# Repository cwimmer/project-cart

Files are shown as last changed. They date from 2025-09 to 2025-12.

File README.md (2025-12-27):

# Project Cart

The Project Cart is designed to hold [Euro Containers](https://en.wikipedia.org/wiki/Euro_container) (nominal size 400×300 mm or smaller) to organize project parts and tools. This cart provides a convenient storage solution for multiple projects at your workbench. To switch projects, simply return parts to their containers or place them on the cart, then roll it away. Roll in another cart to continue working seamlessly.

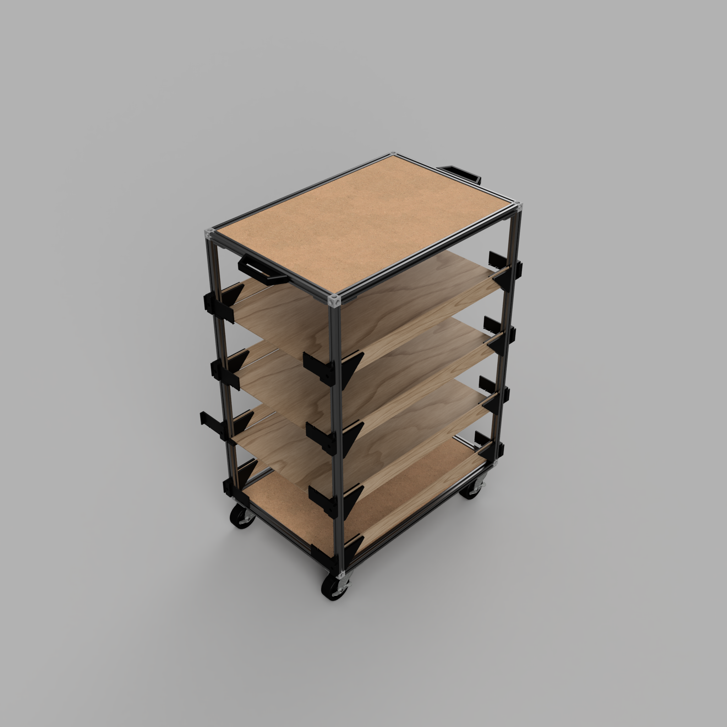
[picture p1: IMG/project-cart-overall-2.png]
Wheeled project cart with multiple shelves holding Euro containers in a workshop setting, featuring a black aluminum frame with yellow casters and organized storage compartments


Please use the [latest released version](https://github.com/cwimmer/project-cart/releases/latest).  The main branch might have partial changes committed.

## Capabilities required to build this project

- Metric hex wrenches
- Large square
- FDM 3D Printer
- Ability to cut sheet goods square to accurate dimensions
  - Table saw or track saw are easiest.  Other methods will work.
- Metric ruler (800mm or longer)

## Table of Contents

- [Readme](README.md) - This file
- [Bill of Materials](BOM.md) - Specifications of parts included in this assembly
- [Assembly Instructions](ASSEMBLY.md) - Assembly Instructions
- [Changelog](CHANGELOG.md) - Chronologically ordered list of notable changes for each version of a project
- [Material Defaults](MATERIAL_DEFAULTS.md) - Descriptions of materials where not otherwise specified.
- [Part Orientation](PART_ORIENTATION.md) - Orientation instructions for 3D printing
- [On Suppliers](ON_SUPPLIERS.md) - Discussion of how to source parts for this assembly
- [Acknowledgements](ACKNOWLEDGEMENTS.md) - Acknowledgements of other authors included either for reference or inspiration

## General Notes

1. Unless otherwise specified, dimensions are in millimeters.
2. The CAD diagrams in the CAD directory are the authoritative definition of this assembly.

## License

Unless otherwise noted:

- **All written content and images:** © Charles Wimmer, licensed under [Creative Commons Attribution 4.0 International](https://creativecommons.org/licenses/by/4.0/).
- **All hardware design files (e.g., STL, CAD, PCB):** Licensed under the [CERN Open Hardware License v2 – Strongly Reciprocal](https://ohwr.org/cern_ohl_s_v2.txt).
- **All code and scripts:** Licensed under the [MIT License](https://opensource.org/licenses/MIT).

## Images

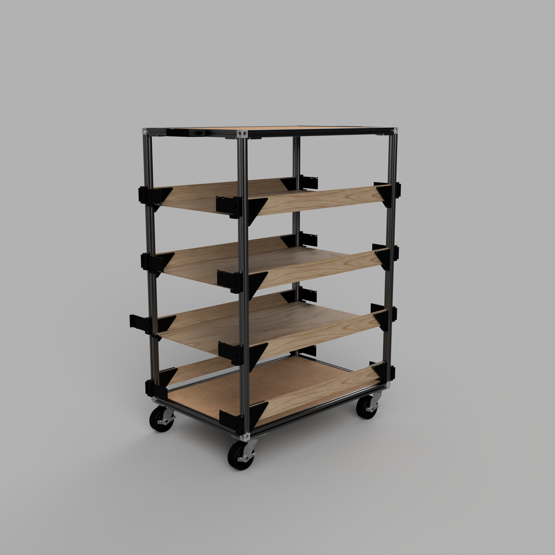
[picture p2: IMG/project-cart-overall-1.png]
Overall 1

Overall 2
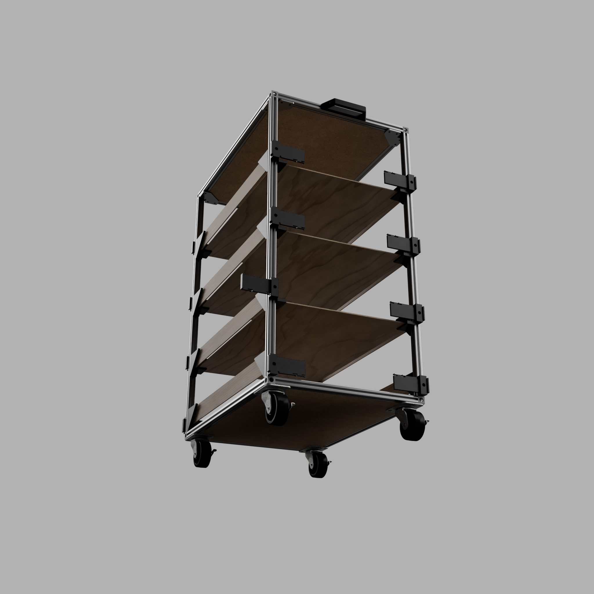
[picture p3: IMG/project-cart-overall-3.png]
Overall 3

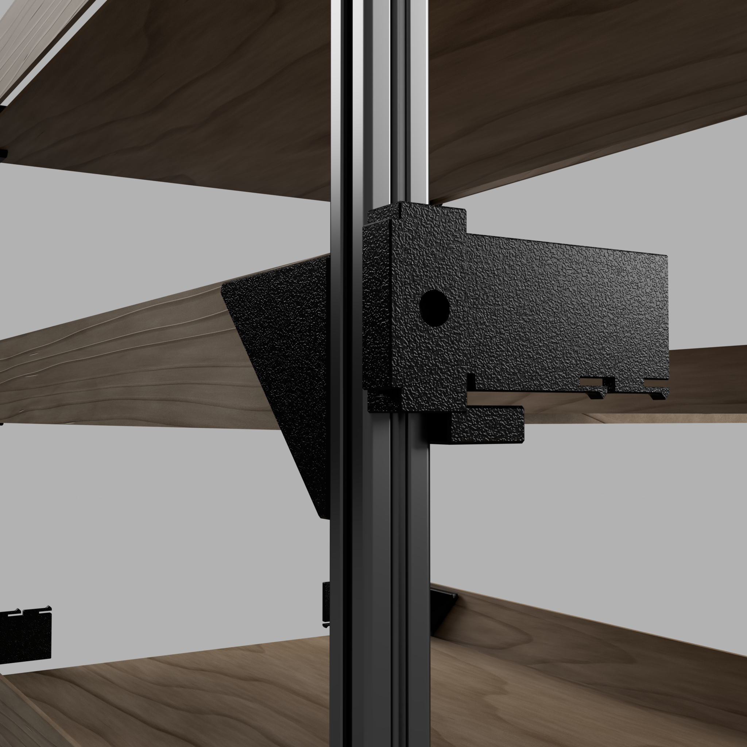
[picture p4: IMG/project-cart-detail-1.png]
Detail 1

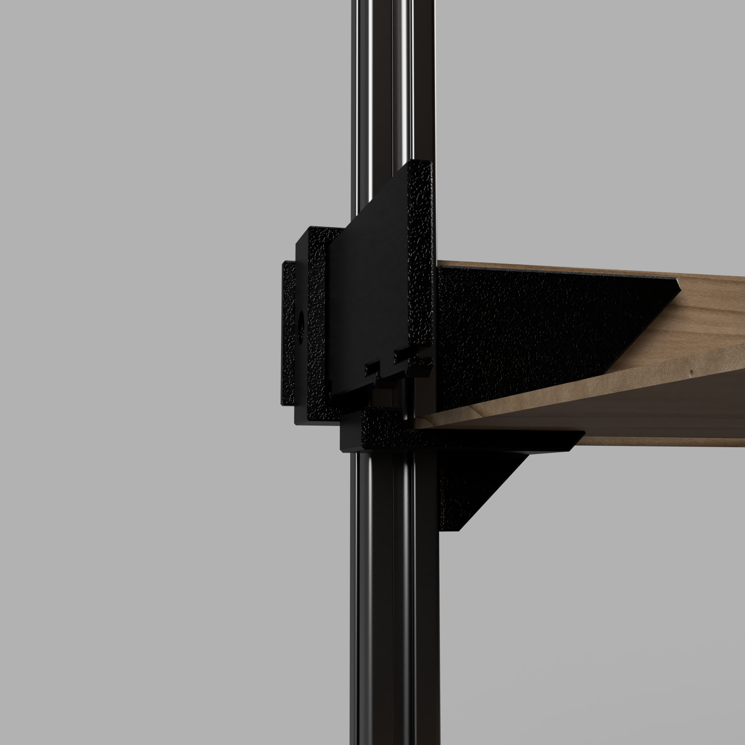
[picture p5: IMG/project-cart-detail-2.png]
Detail 2

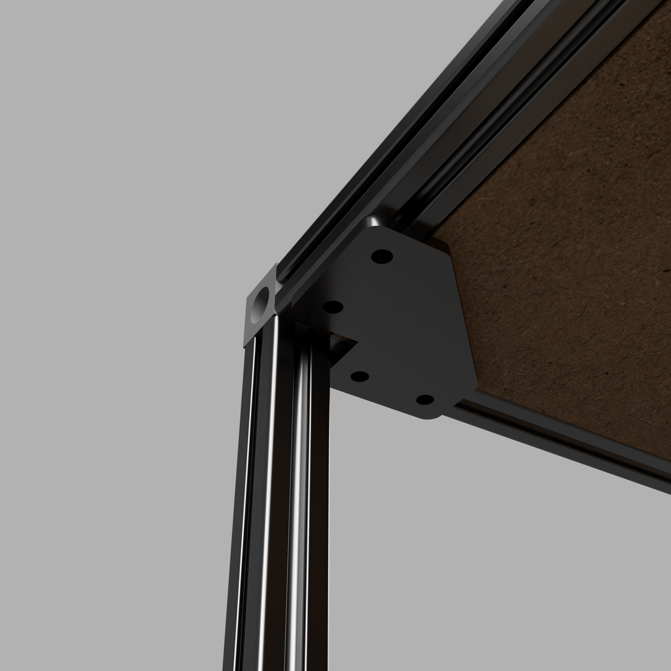
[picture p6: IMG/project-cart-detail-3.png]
Detail 3

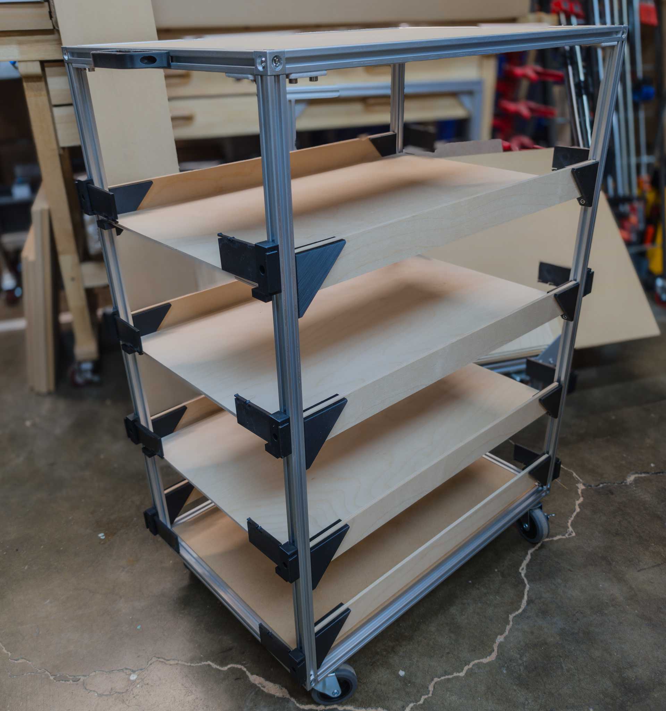
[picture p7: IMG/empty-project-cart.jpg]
Real Image empty

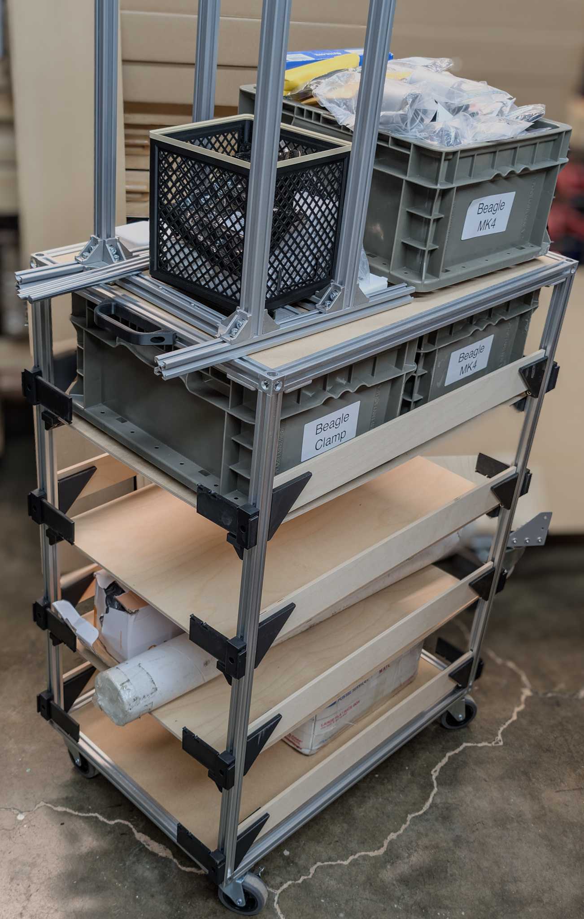
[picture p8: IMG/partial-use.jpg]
Partial use


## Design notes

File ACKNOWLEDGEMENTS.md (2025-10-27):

# Acknowledgements

- [Corner Cube](https://grabcad.com/library/corner-cube-vslot-2020-3-ways-1) model by [Steepy](https://grabcad.com/steepy-1)
- [Caster](https://www.mcmaster.com/2358t26/) model by McMaster
- [Extrusion](https://www.mcmaster.com/5537T9) model by McMaster
- [Keep a Changelog](https://keepachangelog.com/en/1.1.0/)

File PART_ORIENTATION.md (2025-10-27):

# Part Orientation

These parts have been successfully printed using [Voron Print Settings](https://docs.vorondesign.com/sourcing.html) in ASA.

Orient with the long diagonal side on the print bed to resist layer line separation under load.

## PC-001/PC-002 Shelf Bracket

- 12 × 2020 Shelf Bracket ([STEP](STEP)/[STL](STL))
  - Mirror 6 of them.  Left are different from right.

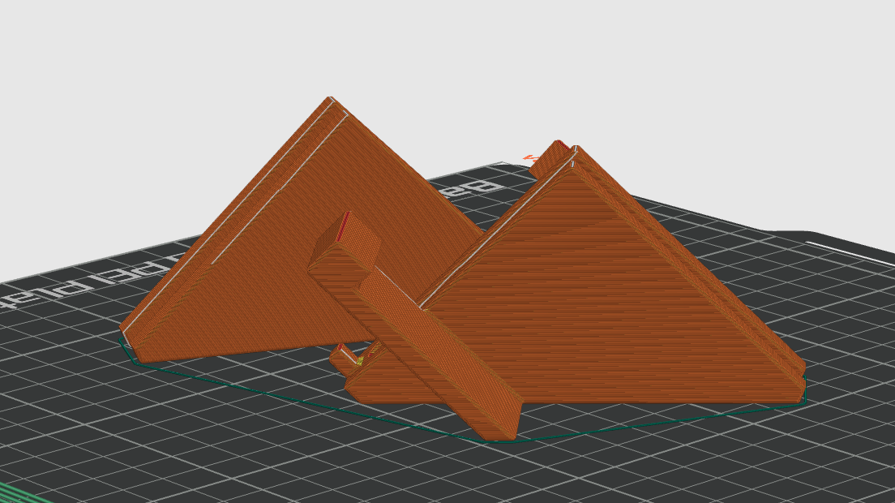
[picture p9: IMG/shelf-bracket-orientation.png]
Shelf Bracket


## PC-003 Side Bracket

- 4 × 2020 Side Bracket ([STEP](STEP)/[STL](STL))

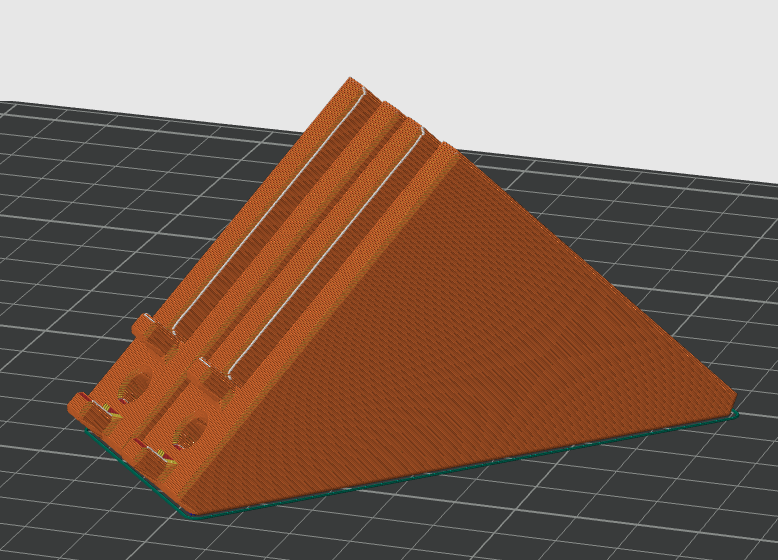
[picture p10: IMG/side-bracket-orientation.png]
Side Bracket


## PC-004 Latch

- 16 x 2020 Latch ([STEP](STEP)) Optional, but suggested.
  - Must split the STEP file into separate objects to print.
  - Supports are integrated into the model and must be removed before installation

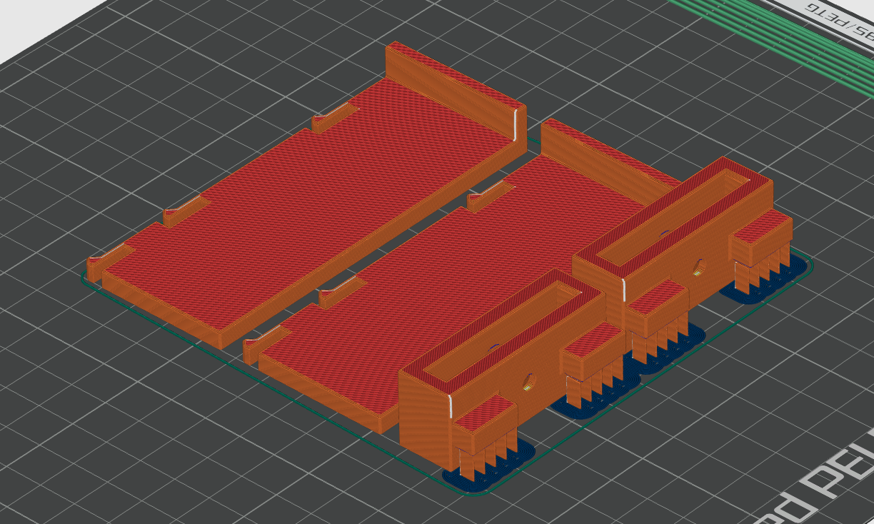
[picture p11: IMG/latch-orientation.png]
Latch


## PC-005 Shelf Bracket Spacer

- 1 x Shelf Bracket Spacer([STEP](STEP)/[STL](STL)). Optional, but suggested.

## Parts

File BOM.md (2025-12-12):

# Bill of Materials

Most components are listed from McMaster for convenience; feel free to substitute equivalent items from other suppliers.

The [2020 Corner Shelf Supports](https://github.com/cwimmer/2020-corner-shelf-support) (PC-109) are a part I designed.  You can produce your own or [contact me](https://the-playground.net/Whoami) if you would to purchase some.  These may theoretically be 3D printed, but I wouldn't suggested for any but the lightest laod.

## 3D Printed Components

| Part Number | Common Name | Quantity | Description | Material | Finish | Sources | Notes |
| --- | --- | --- | --- | --- | --- | --- | --- |
| PC-001 | Shelf Bracket Left | 6 | Support bracket for internal shelf and side panel | ASA (Substitute as needed) | | [STL](STL)/[STEP](STEP)/[CAD](CAD) | See [PART_ORIENTATION.md](PART_ORIENTATION.md) |
| PC-002 | Shelf Bracket Right | 6 | Support bracket for internal shelf and side panel | ASA (Substitute as needed) | | [STL](STL)/[STEP](STEP)/[CAD](CAD) | See [PART_ORIENTATION.md](PART_ORIENTATION.md) |
| PC-003 | Side Bracket | 4 | Support bracket for bottom shelf side panel | ASA (Substitute as needed) | | [STL](STL)/[STEP](STEP)/[CAD](CAD) | See [PART_ORIENTATION.md](PART_ORIENTATION.md) |
| PC-004 | Latch | 16 | Widgets to perform foo | ASA (Substitute as needed) | | [STL](STL)/[STEP](STEP)/[CAD](CAD) | See [PART_ORIENTATION.md](PART_ORIENTATION.md) |
| PC-005 | Shelf Bracket Spacer | 1 | Assembly jig | Any | | [STL](STL)/[STEP](STEP)/[CAD](CAD) | |

## Non-fasteners

| Part Number | Common Name | Quantity | Description | Material | Finish | Sources | Notes |
| --- | --- | --- | --- | --- | --- | --- | --- |
| PC-101 | 800mm aluminum extrusion| 4 | 2020 t-slot aluminum extrusion | Aluminum alloy (Magnesium and Silicon 6xxx ) | Any |McMaster: [5537T9](https://www.mcmaster.com/5537T9)<br>Amazon US: [B08PQTDPB3](https://www.amazon.com/dp/B08PQTDPB3) | |
| PC-102 | 400mm aluminum extrusion| 4 | 2020 t-slot aluminum extrusions | Aluminum alloy (Magnesium and Silicon 6xxx ) | Any | McMaster: [5537T9](https://www.mcmaster.com/5537T9)<br>Amazon US: [B0874387ZB](https://www.amazon.com/dp/B0874387ZB) | |
| PC-103 | 600mm aluminum extrusion | 4 | 2020  t-slot aluminum extrusions | Aluminum alloy (Magnesium and Silicon 6xxx ) | Any |McMaster: [5537T9](https://www.mcmaster.com/5537T9)<br>Amazon US: [B08CN9L94Q](https://www.amazon.com/dp/B08CN9L94Q) | |
| PC-104 | Corner Brackets | 8 | Outside Corner Bracket for 20 mm High Single Rail | Aluminum alloy (Magnesium and Silicon 6xxx ) | Any| McMaster: [5537T286](https://www.mcmaster.com/5537T286)<br>Amazon US: [B0CZRH2RW4](https://www.amazon.com/dp/B0CZRH2RW4) |  |
| PC-105 | Casters | 4 | 3 inch diameter solid rubber wheel swivel plate caster.  120lb load minimum | Zinc-Plated Steel and rubber| Any | McMaster [2358T26](https://www.mcmaster.com/2358T26)<br>Amazon US: [B0D8L62MFL](https://www.amazon.com/dp/B0D8L62MFL) |  |
| PC-106 | Interior Shelves | 3| 399mm x 629mm x 3mm (1/8") plywood panel | Baltic birch or similar | Any| [Woodworkers Source](https://www.woodworkerssource.com/plywood/18-baltic-birch-plywood-pack-choose-your-size.html) |  |
| PC-107 | Side Panels | 8 | 50mm x 599mm x 3mm (1/8") plywood panel | Baltic birch or similar | Any| [Woodworkers Source](https://www.woodworkerssource.com/plywood/18-baltic-birch-plywood-pack-choose-your-size.html) |  |
| PC-108 | Top/Bottom Shelves | 2 | 399mm x 599mm x 18mm (3/4") Plywood or particle board panel | MDF or similar | Any | [Woodworkers Source](https://www.woodworkerssource.com/mdf-34-free-shipping.html) |  |
| PC-109 | 2020 Corner Shelf Brackets | 4 |Custom joining plate for 2020 extrusions |Aluminum alloy (Magnesium and Silicon 6xxx )  | Any | [https://github.com/cwimmer/2020-corner-shelf-support](https://github.com/cwimmer/2020-corner-shelf-support)<br>- 3D Printed (NOT SUGGESTED)<br>- CNC yourself<br>- [Contact me](https://the-playground.net/Whoami) to acquire |  |

## Fasteners

| Part Number | Common Name | Quantity | Description | Material | Finish | Sources | Notes |
| --- | --- | --- | --- | --- | --- | --- | --- |
| **M6** | | | | | | | |
| PC-201 | M6 x 12mm BHCS | 24 | M6 × 1.0 mm thread Stainless Steel Button Head Cap Screws | 18-8 or 304 Stainless Steel | Any | McMaster: [92095A226](https://www.mcmaster.com/92095A226/)<br>Bolt Depot: [6644](https://boltdepot.com/Product-Details?product=6644) |  |
| PC-202 | M6 x 30mm SHCS | 4 | M6 × 1.0 mm thread Stainless Steel Socket Head Cap Screws | 18-8 or 304 Stainless Steel |Any|McMaster: [91292A139](https://www.mcmaster.com/91292A139/)<br>Bolt Depot: [6421](https://boltdepot.com/Product-Details?product=6421) | |
| PC-203  | M6 Washers | 4 | M6 General Purpose Washers| 18-8 or 304 Stainless Steel | Any| McMaster: [93475A250](https://www.mcmaster.com/93475A250/)<br>Bolt Depot: [4516](https://boltdepot.com/Product-Details?product=4516)| |
| **M5** | | | | |
|PC-204 | M5 x 8mm SHCS | 16| M5 × 0.8 mm thread Stainless Steel Socket Head Cap Screws | 18-8 or 304 Stainless Steel | Any| McMaster: [91292A191](https://www.mcmaster.com/91292A191/)<br>Bolt Depot: [6406](https://boltdepot.com/Product-Details?product=6406) |  |
|PC-205  | M5 x 14mm SHCS |16| M5 × 0.8 mm thread Stainless Steel Socket Head Cap Screws | 18-8 or 304 Stainless Steel |Any| McMaster: [91292A058](https://www.mcmaster.com/91292A058/)<br>Bolt Depot: [20261](https://boltdepot.com/Product-Details?product=20261) |  |
|PC-206  | M5 Washers | 8 | M5 General Purpose Washers| 18-8 or 304 Stainless Steel |Any|McMaster:  [93475A240](https://www.mcmaster.com/93475A240/)<br>Bolt Depot: [4515](https://boltdepot.com/Product-Details?product=4515)|  |
|PC-207 | 2020 M5 Drop in nuts | 52 | 2020 M5 Hammer Head Nuts | Carbon or Stainless Steel | Any| Amazon US: [B01FOC6A8E](https://www.amazon.com/dp/B01FOC6A8E) | |
|PC-210 | M5 x 10mm SHCS | 8 | M5 × 0.8 mm thread Stainless Steel Socket Head Cap Screws | 18-8 or 304 Stainless Steel | Any| McMaster: [91292A124](https://www.mcmaster.com/91292A124/)<br>Bolt Depot: [6407](https://boltdepot.com/Product-Details?product=6407) |  |
| **M4**| | | | |
| PC-208 | M4 x 10mm FHCS |16|  M4 × 0.7 mm thread Stainless Steel Socket Head Cap Screws | 18-8 or 304 Stainless Steel|Any|McMaster: [91292A116](https://www.mcmaster.com/91292A116/)<br>Bolt Depot: [6664](https://boltdepot.com/Product-Details?product=6664) |  |
| PC-209| 2020 M4 Drop in Nuts | 16| 2020 M4 Drop nuts | Carbon Steel | Any| Amazon US: [B01FOC6ADE](https://www.amazon.com/dp/B01FOC6ADE) | |

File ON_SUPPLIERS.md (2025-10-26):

# On Components and Suppliers

## Suppliers

In the Bill of Materials, I sometimes list McMaster as the supplier.  You do not have to purchase the components from McMaster.  McMaster provides excellent specifications for all of their components.  McMaster links are an easy way to access specifications. You may select equivalent parts from any supplier.

When McMaster does not supply a specific part, I've included links to suppliers I've used.  These parts will fulfill the requirements of this design, but you may select equivalent parts from any supplier.

## Materials

### 3D Printer Filament

As I built my project carts, I selected ASA as the filament.  You may substitute the material of your choice.  Just ensure you understand the material properties meet your load requirements.

### Fasteners

I've specified stainless steel fasteners.  You may choose any material you wish for your fasteners as long as you weigh the material change against your load requirements.

### Plywood

I've chosen MDF and Baltic Birch for the plywood portion of the cart.  I've tested these materials to ensure they meet my load requirements.  Avoid using thin MDF or particleboard for the interior shelves.  It is not strong enough for even the smallest loads.  If you use MDF, it should be a much thicker size, and the Hudson Exchange straight wall containers will no longer fit between the shelves.

## Standards

All fasteners I've used in my testing conform to ISO 4762.

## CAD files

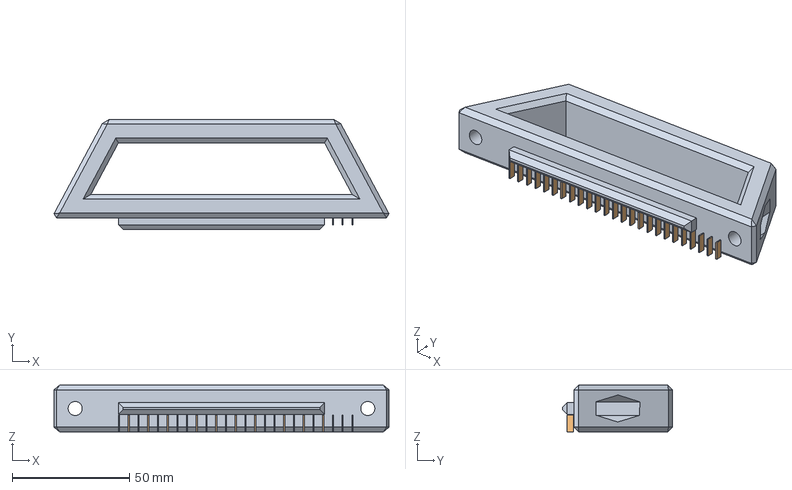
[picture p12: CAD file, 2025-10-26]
STEP/2020 Handle v2.step
143.1 x 47.0 x 20.0 mm

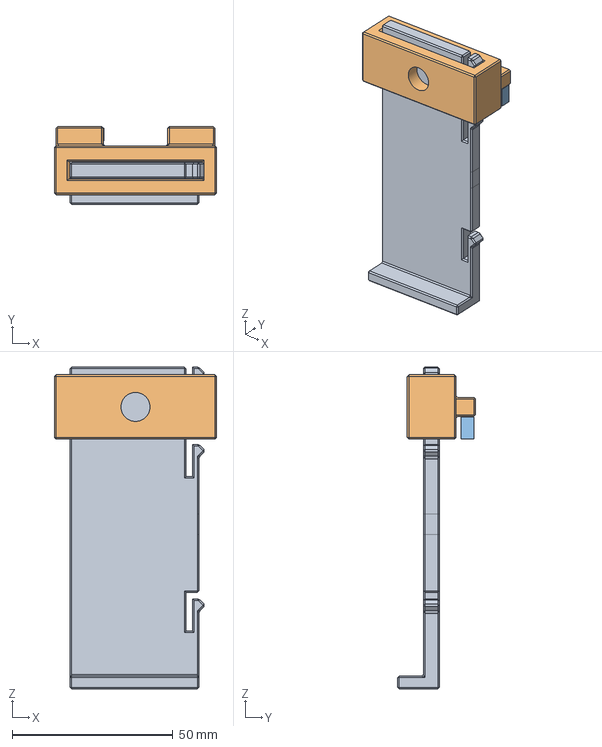
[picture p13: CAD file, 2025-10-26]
STEP/2020 Latch v10.step
50.4 x 24.2 x 100.0 mm
Slider
Anchor

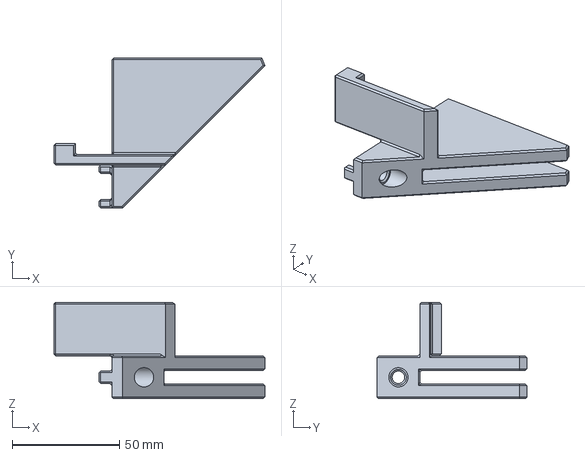
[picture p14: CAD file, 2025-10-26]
STEP/2020 Side Bracket plus shelf support v4.step
98.5 x 70.0 x 45.0 mm

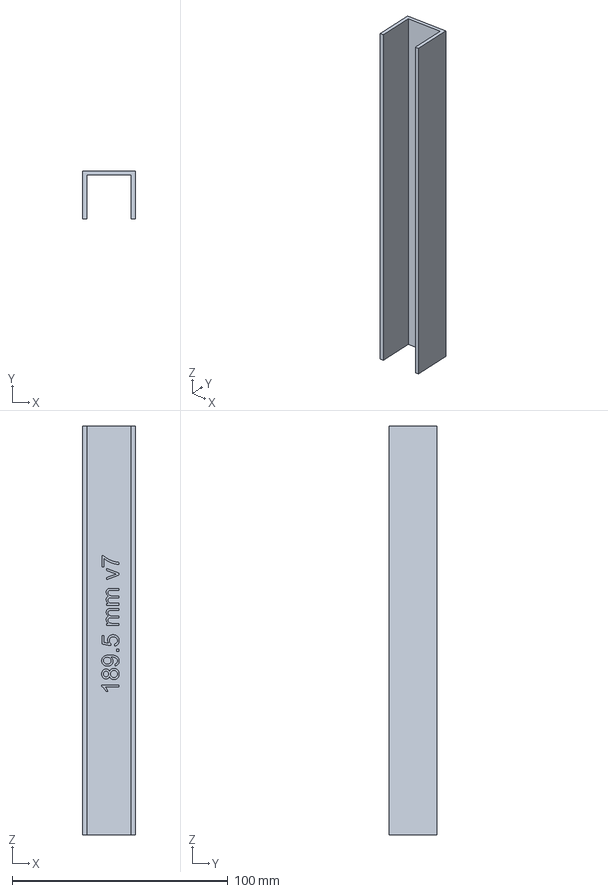
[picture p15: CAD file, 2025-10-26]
STEP/2020 Shelf Bracket Spacer v7.step
24.4 x 22.4 x 189.5 mm

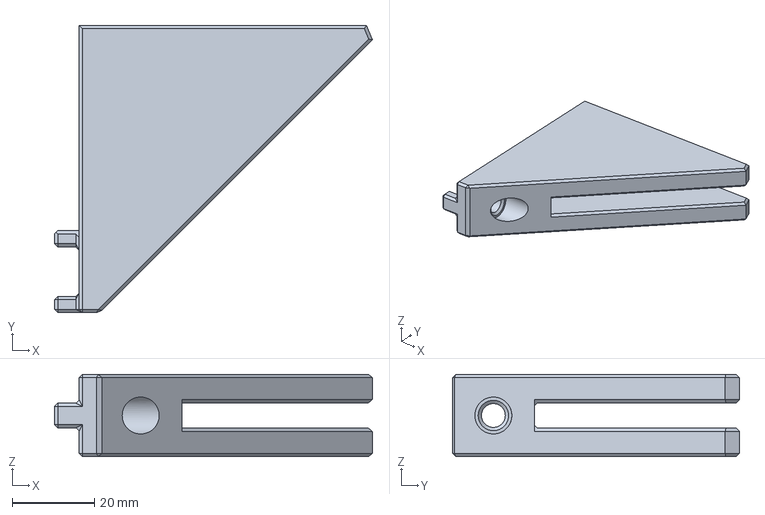
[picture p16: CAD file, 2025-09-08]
STEP/2020 Side Bracket v3.step
77.5 x 70.0 x 20.0 mm

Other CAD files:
STEP/2020 Latch v8.step
CAD/2020 Handle v2.f3d
CAD/2020 Latch v10.f3d
CAD/2020 Shelf Bracket Spacer v7.f3d
CAD/2020 Side Bracket plus shelf support v4.f3d
CAD/2020 Side Bracket v3.f3d
CAD/Project Cart v4 v2.f3z
STL/2020 Handle v2.stl
STL/2020 Latch v10.stl
STL/2020 Shelf Bracket Spacer v7.stl
STL/2020 Side Bracket plus shelf support v4.stl
STL/2020 Side Bracket v3.stl

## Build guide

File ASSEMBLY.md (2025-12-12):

# Assembly Instructions

Refer to the [CAD](CAD) diagrams for detailed part orientation.

## Frame

- [Tap both ends of all extrusions with an M6 tap](https://the-playground.net/Fabrication+Techniques/Tapping+2020+Extrusions); all joints rely on threaded ends.
- Assemble the frame per CAD drawings:
  - Vertical members: 800 mm (PC-101)
  - Width: 400 mm (PC-102)
  - Depth: 600 mm (PC-103)
- Each corner joint uses a Corner Bracket (PC-104) and three M6 × 12 BHCS (PC-201).
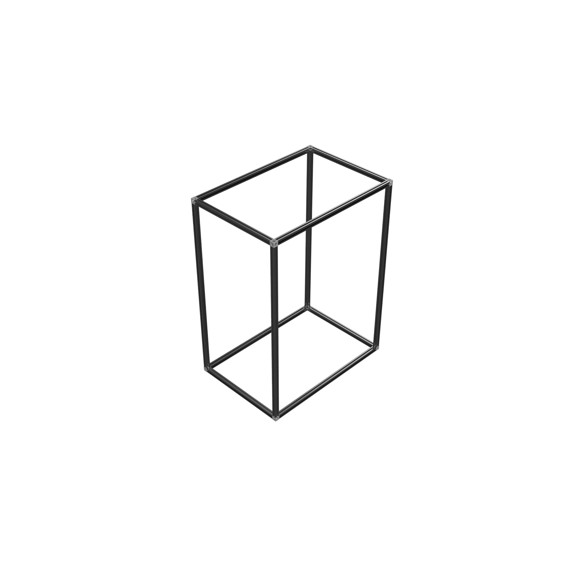
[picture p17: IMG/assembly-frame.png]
Frame


## Casters

- Thread two M5 Drop Nuts (PC-207) partially through each caster corner. Secure using an M5 washer (PC-206) and M5 × 10 mm SHCS (PC-210).
- Remove a screw from an 800 mm vertical member at the corner. Replace it with an M6 × 30 mm screw (PC-202) and M6 washer (PC-203), securing the caster.
- Attach both the M5 drop nuts and M6 screw simultaneously to fasten the caster to the extrusion.
- Repeat for all four casters.
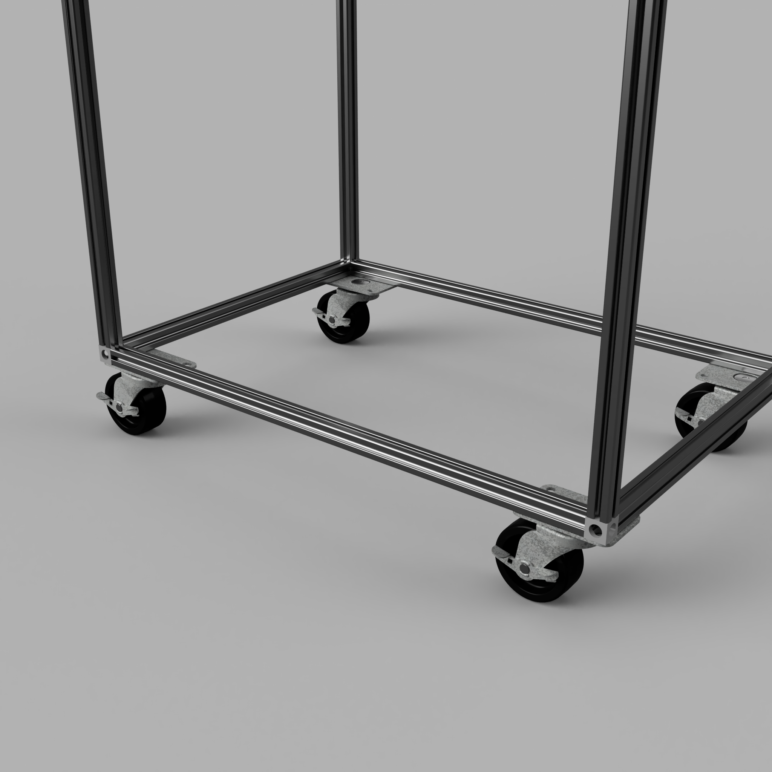
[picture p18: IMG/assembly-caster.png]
Caster


## Middle Shelves

### Brackets (middle)

Attach the shelf brackets (PC-001/PC-002) to the vertical extrusions, spacing them so the top of each shelf is 200 mm above the one below.

You may use the printed Shelf Bracket Spacer (PC-005) to make installation easier.  Place the spacer on the front of an extrusion resting on top of the plywood of the shelf below.  Install the next shelf bracket by resting it on top of the spacer.
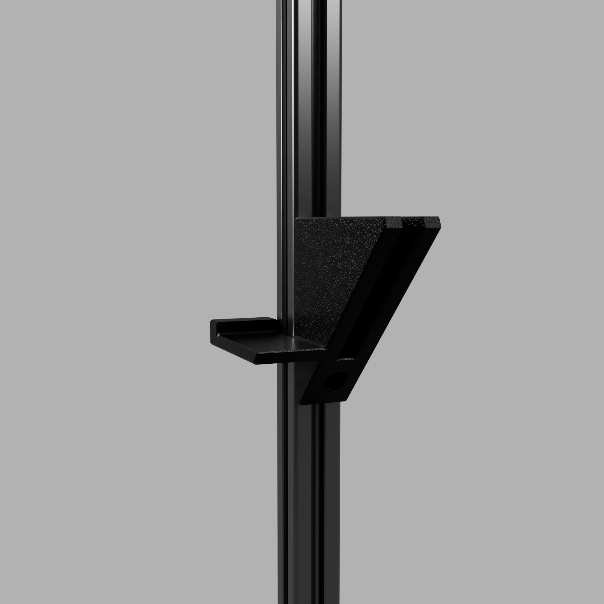
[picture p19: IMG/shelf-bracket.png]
Shelf Bracket


### Plywood (middle)

Drop the shelves (PC-106) onto the brackets. Shelves fit loosely to allow for reconfiguration should you need to transport taller items.

## Side Supports

### Brackets (side)

At the bottom of the cart, install the four side supports (PC-003) flush with the bottom frame.  Install using M5 x 14mm SHCS (PC-205)and 2020 drop nuts (PC-207).
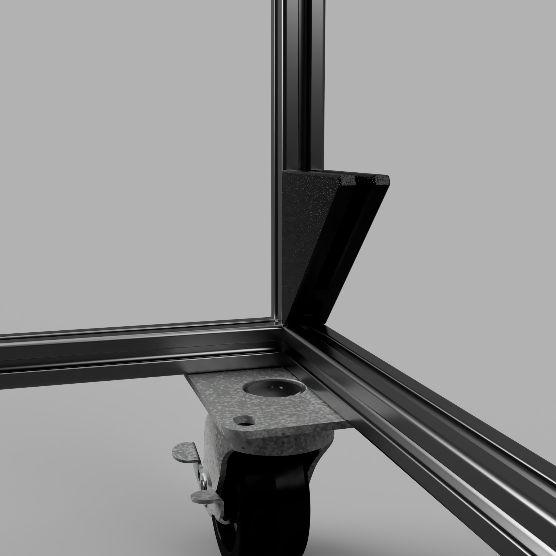
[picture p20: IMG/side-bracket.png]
Black 3D-printed bracket attached to aluminum extrusion frame showing proper installation position for side support plywood panels at bottom of wheeled cart assembly


### Plywood (side)

Slide the thin strips of birch plywood (PC-107) into the brackets.  The side supports fit loosely to allow removal if you need to load or unload the cart from the side.

## Top/Bottom Shelves

### Brackets (top)

- Attach the four 2020 Corner Shelf Supports (PC-109) below the top frame using M5 Drop Nuts (PC-207) and M5 x 8mm SHCS (PC-204).
Close-up view of a metal corner shelf support bracket mounted to aluminum extrusion frame, showing the triangular reinforcement design and mounting hardware used to support plywood shelving in the wheeled project cart assembly

### Plywood (top/bottom)

- Drop the top shelf (PC-108) into the top frome so that it rests on the 2020 Corner Shelf Supports.
- Drop the bottom shelf (PC-108) into the bottom frame so that it rests on the casters.
- Shelves fit loosely to allow for reconfiguration should you need to transport taller items.

## Latches (Optional)

Attach latches (PC-004) to both sides front and back just above shelves.  Use M4 x 10mm FHCS (PC-208) and M4 drop nuts (PC209).  Remove the latch insert from the latch housing before attempting to insert FHCS.
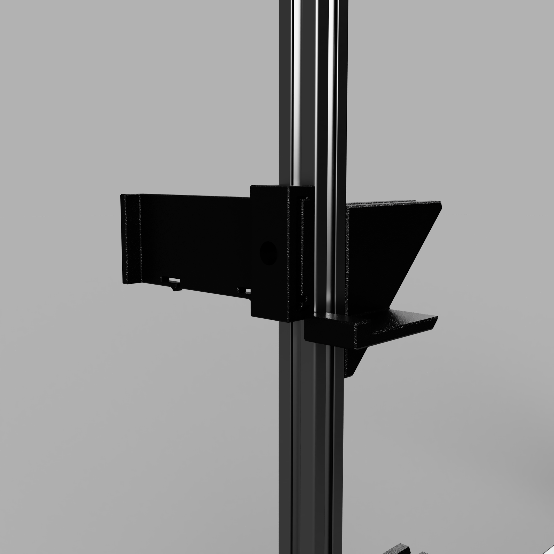
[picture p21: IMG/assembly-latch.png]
Latch


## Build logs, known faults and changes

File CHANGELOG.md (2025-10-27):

# Changelog

All notable changes to this project will be documented in this file.

The format is based on [Keep a Changelog](https://keepachangelog.com/en/1.1.0/).

## [Unreleased]

### Added

### Fixed

### Changed

### Removed

## [v4] - 2025-10-26

### Added

- Added shelf bracket spacer to make shelf support installation easier
- Added real photographic images to the renders
- Added print orientation page
- Added images below each assembly step
- Added optional handle for front and rear

### Changed

- Combined side support and shelf support brackets into one

## [v3] - 2025-10-10

### Added

- Added latch to secure containers in front and rear
  - Latches are removable
  - Slide open and closed
  - Held in place by compliant mechanism

## [v2] - 2025-09-08

### Added

- Side Supports added

### Changed

- Width changed from 610mm to 440mm
- Top changed from 35mm overhands to inset in frame
- Bottom changed from 3mm birch plywood to 18mm MDF inset in frame

## [v1] - 2025-08-27

Initial revision

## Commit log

2025-08-22 Initial Revision
    [2020 front bracket v4.f3d, 2020 front bracket v4.step, 2020 front bracket v4.stl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]
2025-09-08 Release version 2
    [2020 Side Bracket v3.f3d, 2020 Side Bracket v3.step, 2020 Side Bracket v3.stl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]
2025-09-27 Corrected screw lengths
2025-10-05 Reorganized Fastener table in BOM.
2025-10-09 Started adding latches for v3
    [2020 Latch v8.f3d, 2020 Latch v8.step, 2020 Latch v8.stl]
2025-10-10 Releasing version 3
    [2020 Latch v8.f3d, 2020 Latch v9.f3d, Project Cart v2 v8.f3z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]
2025-10-12 Add discussion of materials and suppliers.
2025-10-14 Added spacer to make shelf bracket installation easier.
    [2020 Shelf Bracket Spacer v5.f3d, 2020 Shelf Bracket Spacer v5.step]
2025-10-16 Corrected STL for Shelf Bracket Spacer
    [2020 Shelf Bracket Spacer v5.step, 2020 Shelf Bracket Spacer v5.stl]
2025-10-26 Changes for v4 Release
    [2020 Handle v2.f3d, 2020 Handle v2.step, 2020 Handle v2.stl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]
